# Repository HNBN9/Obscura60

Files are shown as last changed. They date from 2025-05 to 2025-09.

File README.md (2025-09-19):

# Obscura60
first keyboard build 60% wireless

<p align="center">
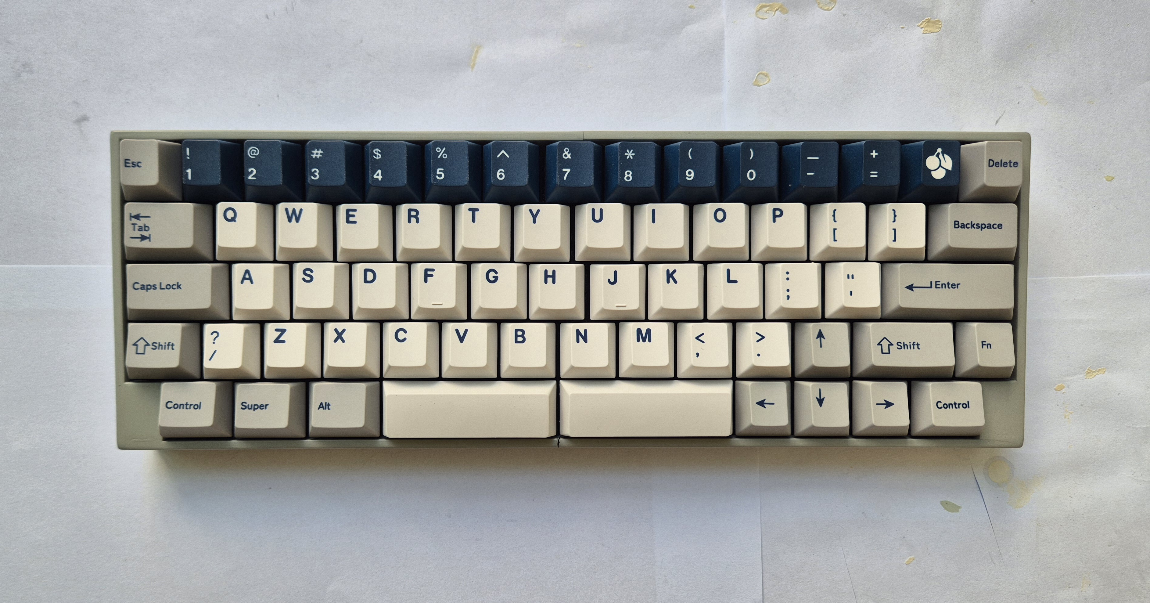
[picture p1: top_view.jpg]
 
</p>

<p align="center">
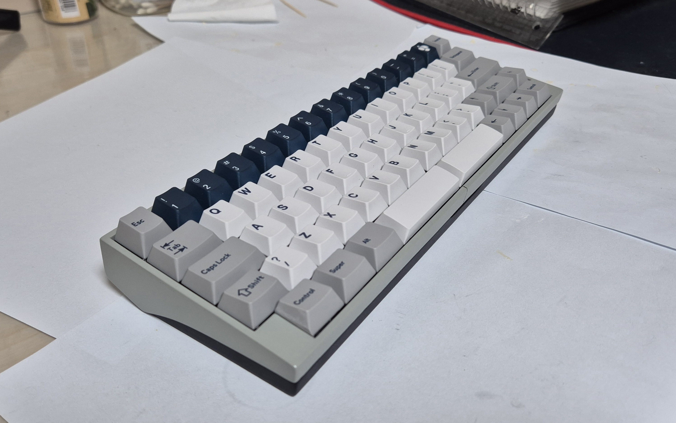
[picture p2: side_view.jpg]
 
</p>

Colored By -<br>
Mr.Finishing Surfacer 1500 Black<br>
Tamiya TS81 - top<br>
Tamiya TS55 - bottom<br>

Keycaps - 日当午GMK Prussian Alert普鲁(ordered 1 more 3u spacebar)<br>

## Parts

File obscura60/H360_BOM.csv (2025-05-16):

Comment | Reference | Footprint | LCSC Part Number
4.7u | C3,C4,C5 | Capacitor_SMD:C_0603_1608Metric | C19666
1u | C6,C7 | Capacitor_SMD:C_1206_3216Metric | C15850
100n | C8 | Capacitor_SMD:C_0402_1005Metric | C1525
D_Small | D3,D4,D5,D6,D7,D8,D9,D10,D11,D12,D13,D14,D15,D16,D17,D18,D19,D20,D21,D22,D23,D24,D25,D26,D27,D28,D29,D30,D31,D32,D33,D34,D35,D36,D37,D38,D39,D40,D41,D42,D43,D44,D45,D46,D47,D48,D49,D50,D51,D52,D53,D54,D55,D56,D57,D58,D59,D60,D61,D62,D63,D64,D65,D66,D67 | Diode_SMD:D_SOD-123 | C81598
MF-MSMF075-2 | F1 | Resistor_SMD:R_1812_4532Metric | C84140
BLM15PX121SN1D | L1 | Inductor_SMD:L_0402_1005Metric | C88970
2N7002 | Q1 | Package_TO_SOT_SMD:SOT-23 | C8545
5.1k | R1,R2 | Resistor_SMD:R_0402_1005Metric | C25905
3.4k | R3 | Resistor_SMD:R_0603_1608Metric | C25804
1.5k | R4 | Resistor_SMD:R_0402_1005Metric | C25867
10k | R5,R7,R8,R9 | Resistor_SMD:R_0402_1005Metric | C25744
47k | R6 | Resistor_SMD:R_0402_1005Metric | C25792
100R | R10 | Resistor_SMD:R_0402_1005Metric | C25076
TS-1187-A-B-A-B | SW2,SW3 | Button_Switch_SMD:SW_Push_1P1T_XKB_TS-1187A | C318884
SRV05-4-P-T7 | U1 | Package_TO_SOT_SMD:SOT-23-6 | C85364
XC6206P332MR-G | U4 | Package_TO_SOT_SMD:SOT-23-3 | C5446
BQ24075RGT | U5 | Package_DFN_QFN:VQFN-16-1EP_3x3mm_P0.5mm_EP1.6x1.6mm | C15464

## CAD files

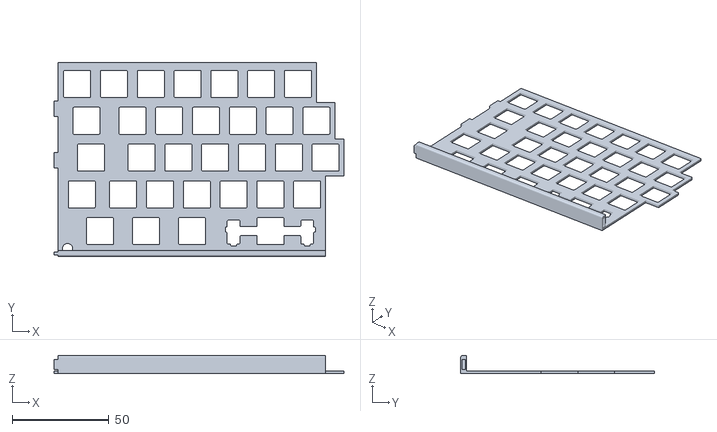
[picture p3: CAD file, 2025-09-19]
3dprint/ltop.stl
150.1 x 100.2 x 9.50

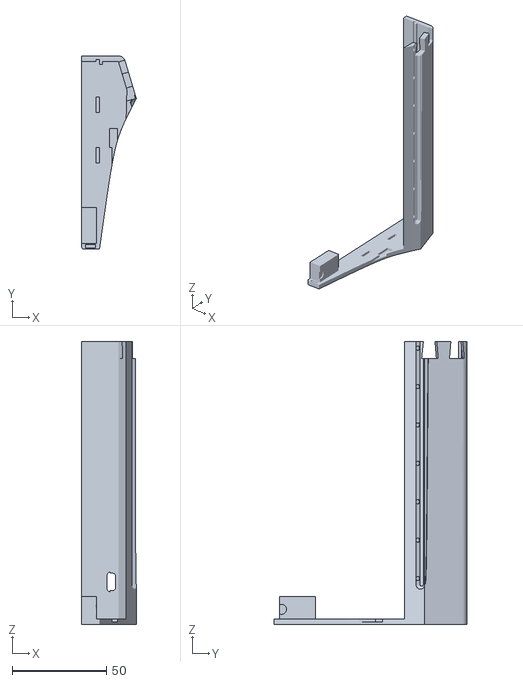
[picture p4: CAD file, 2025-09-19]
3dprint/lside.stl
29.0 x 102.2 x 149.9

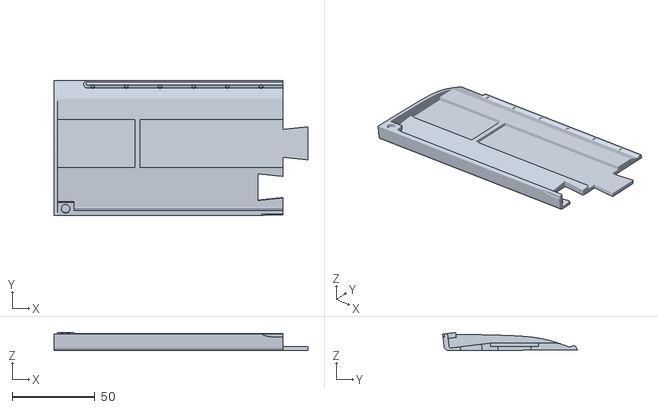
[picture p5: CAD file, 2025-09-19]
3dprint/lbot.stl
153.4 x 81.5 x 10.9

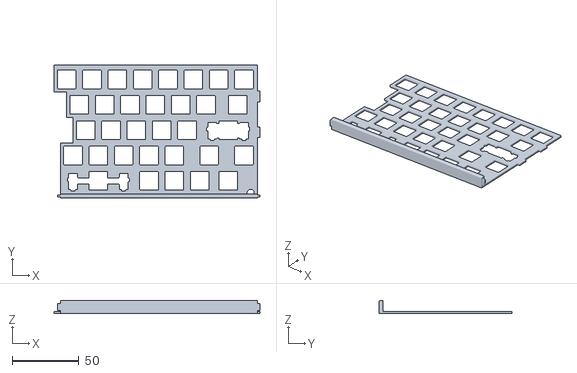
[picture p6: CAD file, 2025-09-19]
3dprint/rtop.stl
154.9 x 100.2 x 9.50

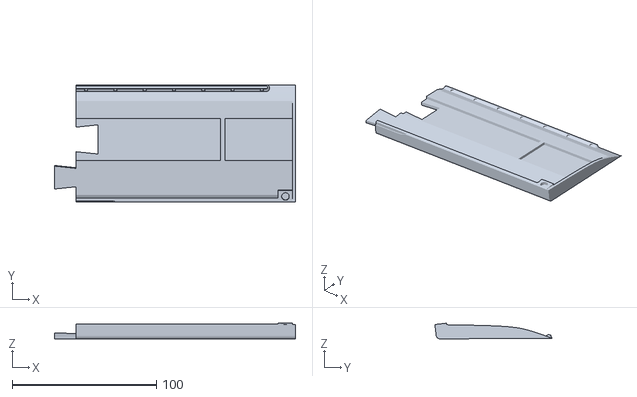
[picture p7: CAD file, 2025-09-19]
3dprint/rbot.stl
167.3 x 81.5 x 10.9

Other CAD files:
3dprint/rside.stl

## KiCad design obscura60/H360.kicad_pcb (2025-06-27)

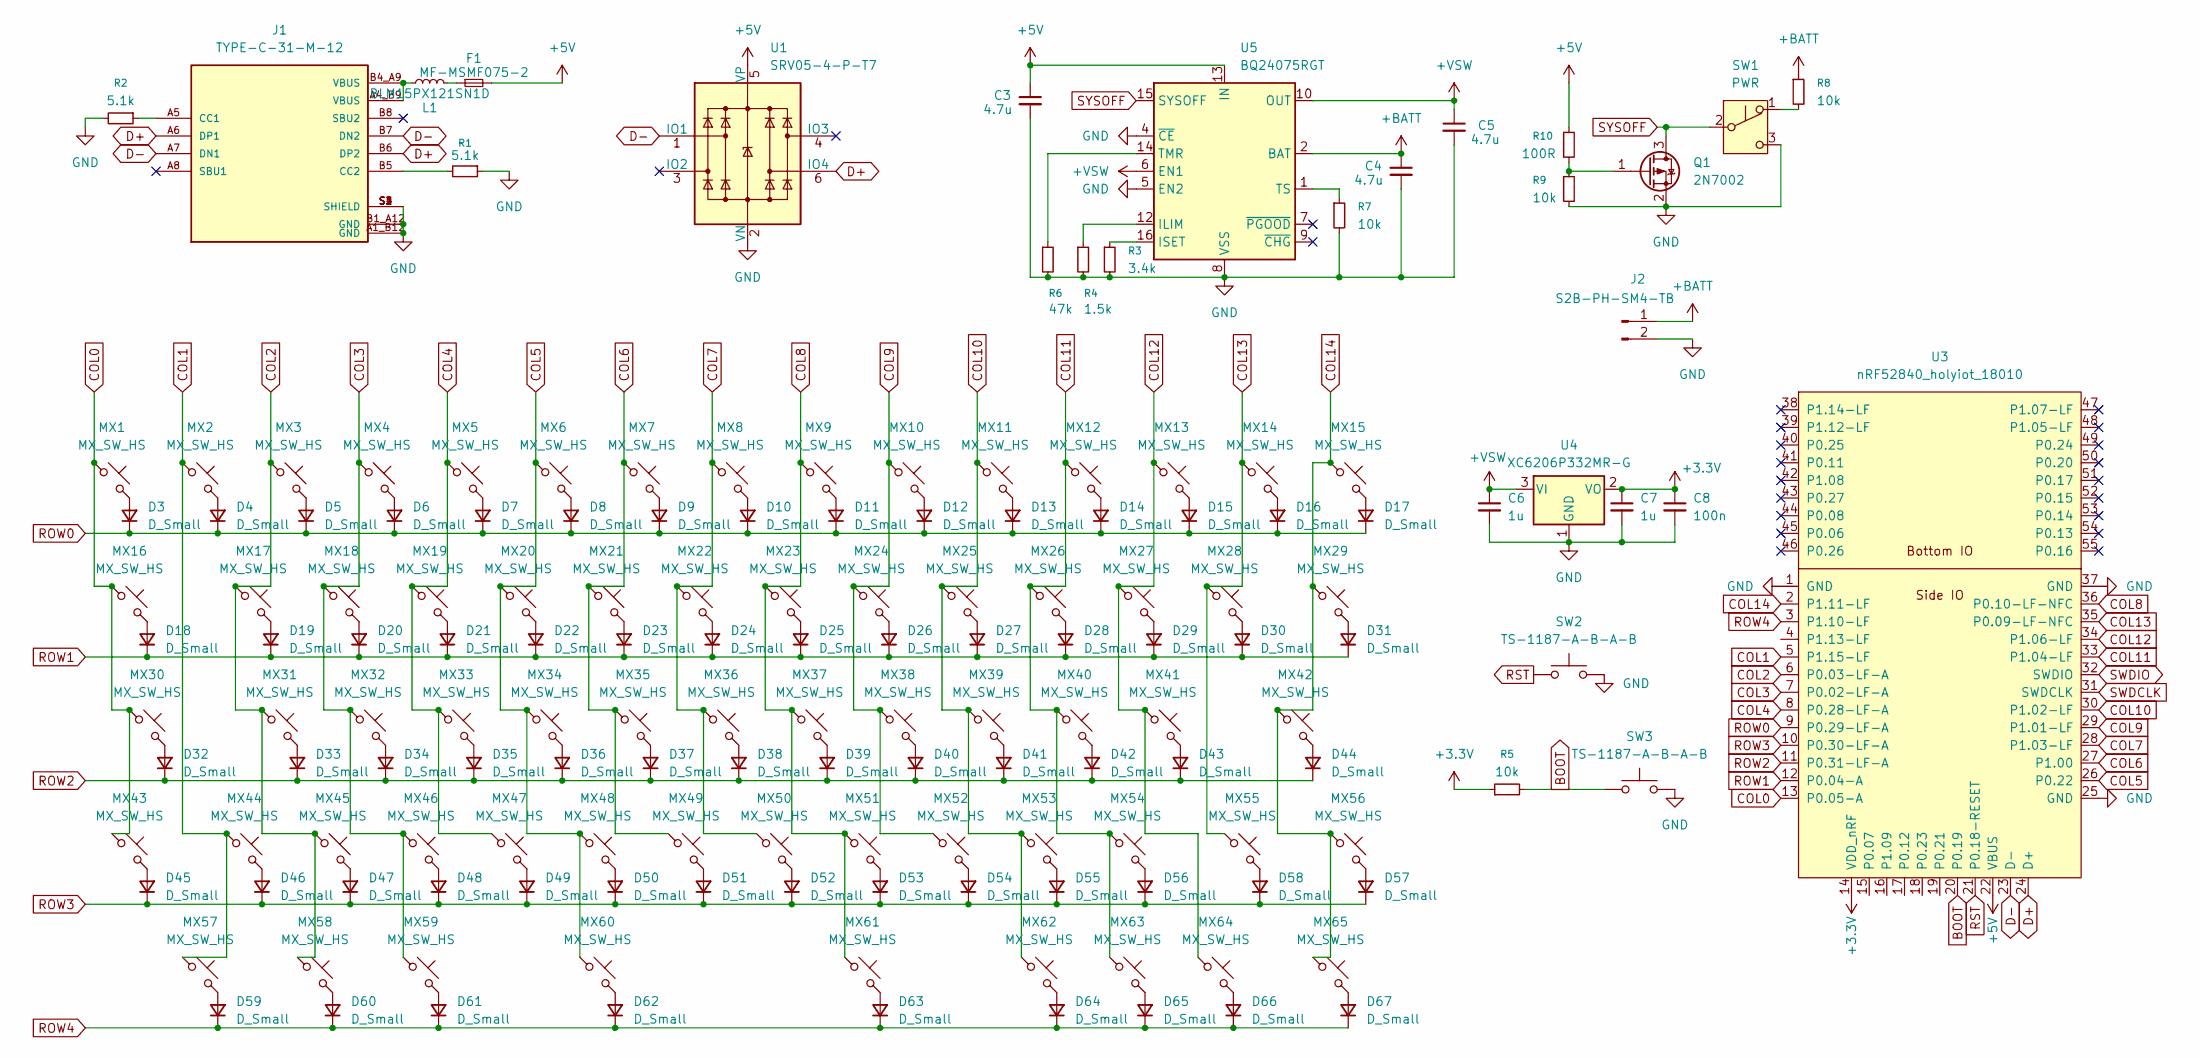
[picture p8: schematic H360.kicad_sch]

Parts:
C3, C4, C5: 4.7u; C_0603_1608Metric
C6, C7: 1u; C_1206_3216Metric
C8: 100n; C_0402_1005Metric
D3, D4, D5, D6, D7, D8, D9, D10, D11, D12, D13, D14, D15, D16, D17, D18, D19, D20, D21, D22, D23, D24, D25, D26, D27, D28, D29, D30, D31, D32, D33, D34, D35, D36, D37, D38, D39, D40, D41, D42, D43, D44, D45, D46, D47, D48, D49, D50, D51, D52, D53, D54, D55, D56, D57, D58, D59, D60, D61, D62, D63, D64, D65, D66, D67: D_Small; D_SOD-123
F1: MF-MSMF075-2; R_1812_4532Metric
J1: TYPE-C-31-M-12; HRO_TYPE-C-31-M-12; PARTREV 2020.12.08
J2: S2B-PH-SM4-TB; JST_PH_S2B-PH-SM4-TB_1x02-1MP_P2.00mm_Horizontal
L1: BLM15PX121SN1D; L_0402_1005Metric
MX1, MX2, MX3, MX4, MX5, MX6, MX7, MX8, MX9, MX10, MX11, MX12, MX13, MX14, MX15, MX16, MX17, MX18, MX19, MX20, MX21, MX22, MX23, MX24, MX25, MX26, MX27, MX28, MX29, MX30, MX31, MX32, MX33, MX34, MX35, MX36, MX37, MX38, MX39, MX40, MX41, MX42, MX43, MX44, MX45, MX46, MX47, MX48, MX49, MX50, MX51, MX52, MX53, MX54, MX55, MX56, MX57, MX58, MX59, MX60, MX61, MX62, MX63, MX64, MX65: MX_SW_HS; SW_MX_HS_CPG151101S11_1u
Q1: 2N7002; SOT-23
R1, R2: 5.1k; R_0402_1005Metric
R3: 3.4k; R_0603_1608Metric
R4: 1.5k; R_0402_1005Metric
R5, R7, R8, R9: 10k; R_0402_1005Metric
R6: 47k; R_0402_1005Metric
R10: 100R; R_0402_1005Metric
SW1: PWR; SW_SPDT_CK_JS102011SAQN
SW2, SW3: TS-1187-A-B-A-B; SW_Push_1P1T_XKB_TS-1187A
U1: SRV05-4-P-T7; SOT-23-6
U3: nRF52840_holyiot_18010
U4: XC6206P332MR-G; SOT-23-3
U5: BQ24075RGT; VQFN-16-1EP_3x3mm_P0.5mm_EP1.6x1.6mm

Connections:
+3.3V: C7.1, C8.1, R5.1, U3.14 (VDD_nRF), U4.2 (VO)
+5V: C3.1, F1.2, R10.1, U1.5 (VP), U3.22 (VBUS), U5.13 (IN)
+BATT: C4.1, J2.1, R8.1, U5.2 (BAT), U5.3 (BAT)
+VSW: C5.1, C6.1, U4.3 (VI), U5.6 (EN1), U5.10 (OUT), U5.11 (OUT)
BOOT: R5.2, SW3.1, U3.20 (P0.19)
COL0: MX1.1, MX16.1, MX30.1, MX43.1, U3.13 (P0.05-A)
COL1: MX2.1, MX44.1, MX57.1, U3.5 (P1.15-LF)
COL2: MX3.1, MX17.1, MX31.1, MX45.1, MX58.1, U3.6 (P0.03-LF-A)
COL3: MX4.1, MX18.1, MX32.1, MX46.1, MX59.1, U3.7 (P0.02-LF-A)
COL4: MX5.1, MX19.1, MX33.1, MX47.1, U3.8 (P0.28-LF-A)
COL5: MX6.1, MX20.1, MX34.1, MX48.1, MX60.1, U3.26 (P0.22)
COL6: MX7.1, MX21.1, MX35.1, MX49.1, U3.27 (P1.00)
COL7: MX8.1, MX22.1, MX36.1, MX50.1, U3.28 (P1.03-LF)
COL8: MX9.1, MX23.1, MX37.1, MX51.1, MX61.1, U3.36 (P0.10-LF-NFC)
COL9: MX10.1, MX24.1, MX38.1, MX52.1, U3.29 (P1.01-LF)
COL10: MX11.1, MX25.1, MX39.1, MX53.1, MX62.1, U3.30 (P1.02-LF)
COL11: MX12.1, MX26.1, MX40.1, MX54.1, MX63.1, U3.33 (P1.04-LF)
COL12: MX13.1, MX27.1, MX41.1, MX64.1, U3.34 (P1.06-LF)
COL13: MX14.1, MX28.1, MX55.1, U3.35 (P0.09-LF-NFC)
COL14: MX15.1, MX29.1, MX42.1, MX56.1, MX65.1, U3.2 (P1.11-LF)
D+: J1.A6 (DP1), J1.B6 (DP2), U1.6 (IO4), U3.24 (D+)
D-: J1.A7 (DN1), J1.B7 (DN2), U1.1 (IO1), U3.23 (D-)
GND: C3.2, C4.2, C5.2, C6.2, C7.2, C8.2, J1.A1_B12 (GND), J1.B1_A12 (GND), J1.S1 (SHIELD), J1.S2 (SHIELD), J1.S3 (SHIELD), J1.S4 (SHIELD), J2.2, Q1.2 (S), R1.1, R2.2, R3.2, R4.2, R6.2, R7.2, R9.2, SW1.3 (C), SW2.2, SW3.2, U1.2 (VN), U3.1 (GND), U3.25 (GND), U3.37 (GND), U4.1 (GND), U5.4 (~CE), U5.5 (EN2), U5.8 (VSS), U5.17 (VSS)
unnamed: D3.2 (A), MX1.2
unnamed: D4.2 (A), MX2.2
unnamed: D5.2 (A), MX3.2
unnamed: D6.2 (A), MX4.2
unnamed: D7.2 (A), MX5.2
unnamed: D8.2 (A), MX6.2
unnamed: D9.2 (A), MX7.2
unnamed: D10.2 (A), MX8.2
unnamed: D11.2 (A), MX9.2
unnamed: D12.2 (A), MX10.2
unnamed: D13.2 (A), MX11.2
unnamed: D14.2 (A), MX12.2
unnamed: D15.2 (A), MX13.2
unnamed: D16.2 (A), MX14.2
unnamed: D17.2 (A), MX15.2
unnamed: D18.2 (A), MX16.2
unnamed: D19.2 (A), MX17.2
unnamed: D20.2 (A), MX18.2
unnamed: D21.2 (A), MX19.2
unnamed: D22.2 (A), MX20.2
unnamed: D23.2 (A), MX21.2
unnamed: D24.2 (A), MX22.2
unnamed: D25.2 (A), MX23.2
unnamed: D26.2 (A), MX24.2
unnamed: D27.2 (A), MX25.2
unnamed: D28.2 (A), MX26.2
unnamed: D29.2 (A), MX27.2
unnamed: D30.2 (A), MX28.2
unnamed: D31.2 (A), MX29.2
unnamed: D32.2 (A), MX30.2
unnamed: D33.2 (A), MX31.2
unnamed: D34.2 (A), MX32.2
unnamed: D35.2 (A), MX33.2
unnamed: D36.2 (A), MX34.2
unnamed: D37.2 (A), MX35.2
unnamed: D38.2 (A), MX36.2
unnamed: D39.2 (A), MX37.2
unnamed: D40.2 (A), MX38.2
unnamed: D41.2 (A), MX39.2
unnamed: D42.2 (A), MX40.2
unnamed: D43.2 (A), MX41.2
unnamed: D44.2 (A), MX42.2
unnamed: D45.2 (A), MX43.2
unnamed: D46.2 (A), MX44.2
unnamed: D47.2 (A), MX45.2
unnamed: D48.2 (A), MX46.2
unnamed: D49.2 (A), MX47.2
unnamed: D50.2 (A), MX48.2
unnamed: D51.2 (A), MX49.2
unnamed: D52.2 (A), MX50.2
unnamed: D53.2 (A), MX51.2
unnamed: D54.2 (A), MX52.2
unnamed: D55.2 (A), MX53.2
unnamed: D56.2 (A), MX54.2
unnamed: D57.2 (A), MX56.2
unnamed: D58.2 (A), MX55.2
unnamed: D59.2 (A), MX57.2
unnamed: D60.2 (A), MX58.2
unnamed: D61.2 (A), MX59.2
unnamed: D62.2 (A), MX60.2
unnamed: D63.2 (A), MX61.2
unnamed: D64.2 (A), MX62.2
unnamed: D65.2 (A), MX63.2
unnamed: D66.2 (A), MX64.2
unnamed: D67.2 (A), MX65.2
unnamed: F1.1, L1.2
unnamed: J1.A5 (CC1), R2.1
unnamed: J1.B5 (CC2), R1.2
unnamed: J1.A4_B9 (VBUS), J1.B4_A9 (VBUS), L1.1
unnamed: Q1.1 (G), R9.1, R10.2
unnamed: R8.2, SW1.1 (A)
unnamed: R4.1, U5.12 (ILIM)
unnamed: R3.1, U5.16 (ISET)
unnamed: R6.1, U5.14 (TMR)
unnamed: R7.1, U5.1 (TS)
ROW0: D3.1 (K), D4.1 (K), D5.1 (K), D6.1 (K), D7.1 (K), D8.1 (K), D9.1 (K), D10.1 (K), D11.1 (K), D12.1 (K), D13.1 (K), D14.1 (K), D15.1 (K), D16.1 (K), D17.1 (K), U3.9 (P0.29-LF-A)
ROW1: D18.1 (K), D19.1 (K), D20.1 (K), D21.1 (K), D22.1 (K), D23.1 (K), D24.1 (K), D25.1 (K), D26.1 (K), D27.1 (K), D28.1 (K), D29.1 (K), D30.1 (K), D31.1 (K), U3.12 (P0.04-A)
ROW2: D32.1 (K), D33.1 (K), D34.1 (K), D35.1 (K), D36.1 (K), D37.1 (K), D38.1 (K), D39.1 (K), D40.1 (K), D41.1 (K), D42.1 (K), D43.1 (K), D44.1 (K), U3.11 (P0.31-LF-A)
ROW3: D45.1 (K), D46.1 (K), D47.1 (K), D48.1 (K), D49.1 (K), D50.1 (K), D51.1 (K), D52.1 (K), D53.1 (K), D54.1 (K), D55.1 (K), D56.1 (K), D57.1 (K), D58.1 (K), U3.10 (P0.30-LF-A)
ROW4: D59.1 (K), D60.1 (K), D61.1 (K), D62.1 (K), D63.1 (K), D64.1 (K), D65.1 (K), D66.1 (K), D67.1 (K), U3.3 (P1.10-LF)
RST: SW2.1, U3.21 (P0.18-RESET)
SWDCLK: U3.31 (SWDCLK)
SWDIO: U3.32 (SWDIO)
SYSOFF: Q1.3 (D), SW1.2 (B), U5.15 (SYSOFF)

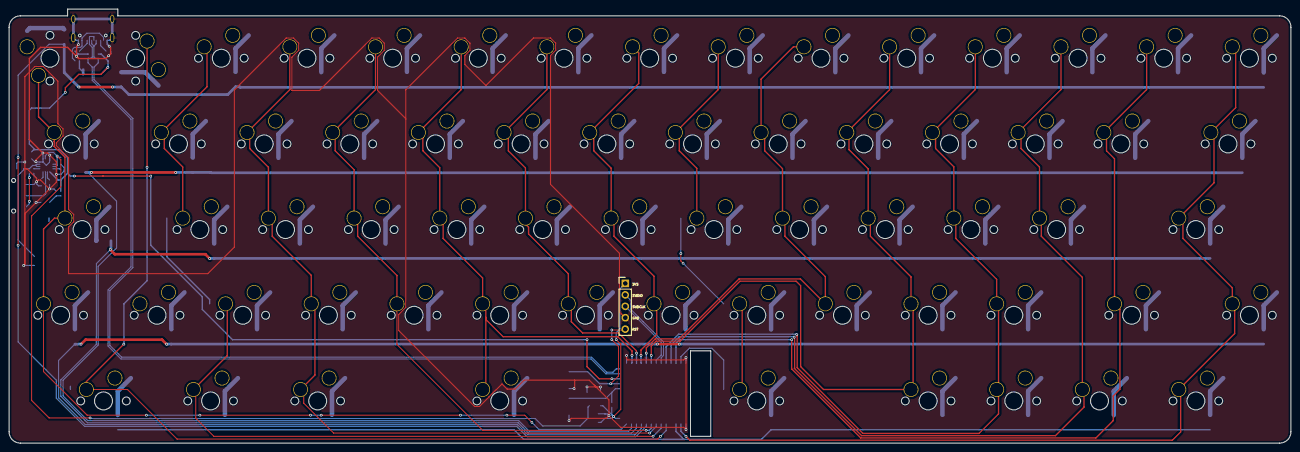
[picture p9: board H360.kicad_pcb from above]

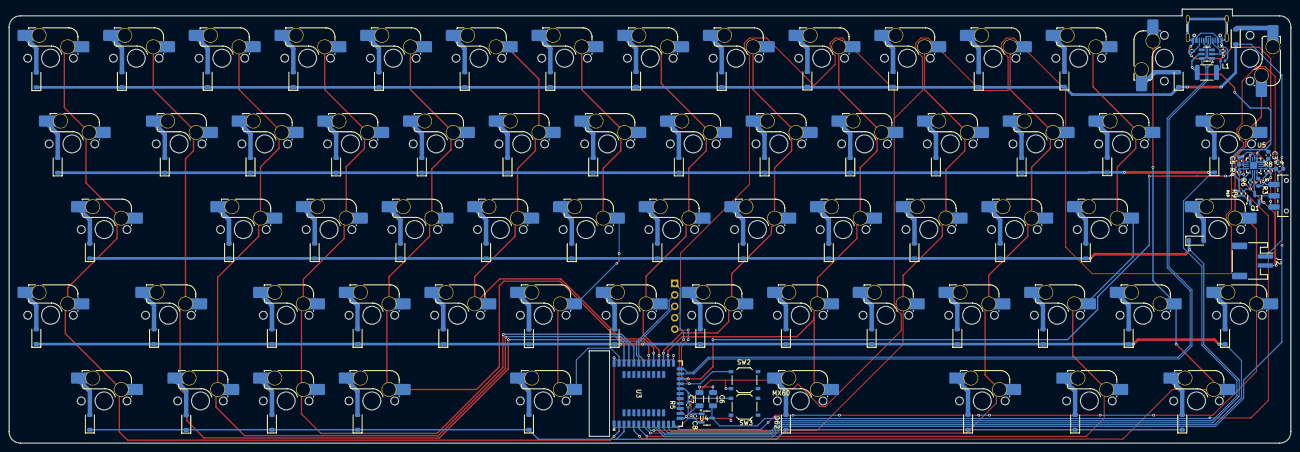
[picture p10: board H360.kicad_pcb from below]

Board: 2 copper layers, 285.0 x 96.5 mm, 158 parts (158 on the bottom side), 105 nets.

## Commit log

2025-04-25 Initialize project
    [H360.kicad_pcb, H360.kicad_sch]
2025-04-28 sch updat4e
    [H360.kicad_sch]
2025-05-03 sch update
    [H360.kicad_sch]
2025-05-03 charger update
    [H360.kicad_sch]
2025-05-11 first final
    [H360.kicad_pcb, H360.kicad_sch]
2025-05-11 3d update
    [H360.kicad_pcb]
2025-05-11 3d re update
    [H360.kicad_pcb]
2025-05-11 small fix
    [H360.kicad_pcb]
2025-05-11 fixed routing
    [H360.kicad_pcb]
2025-05-11 routing fixed
    [H360.kicad_pcb]
2025-06-27 change name
    [H360-B_Adhesive.gbr, H360-B_Courtyard.gbr, H360-B_Cu.gbr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]
2025-07-02 README.md 업데이트
2025-09-19 stl files uploaded
    [lbot.stl, lside.stl, ltop.stl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]
